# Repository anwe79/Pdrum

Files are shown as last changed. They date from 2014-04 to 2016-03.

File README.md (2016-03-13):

Pdrum
=====

These files contain models of parts for an electronic drum kit.
They are written in OpenSCAD.
Any STL files are merely exports of the default configuration of the models.

Users are encouraged to open the files in OpenSCAD and change parameters to suit their needs.
The models are parametric to a certain degree, and should be scaleable to larger sizes, but this has not been tested. 
The default configuration is printable as is on a MendelMax 3D printer (or other printer of equal or greater print area) and suited for 6" heads.

For now, only the drum base + rim and sensor platform is available.
Hi-hat pedal, kick pedal, clamps and DIY stand are in the works, but don't hold your breath :)
Cymbals will be omitted for now, since the angle makes them difficult to print without support.

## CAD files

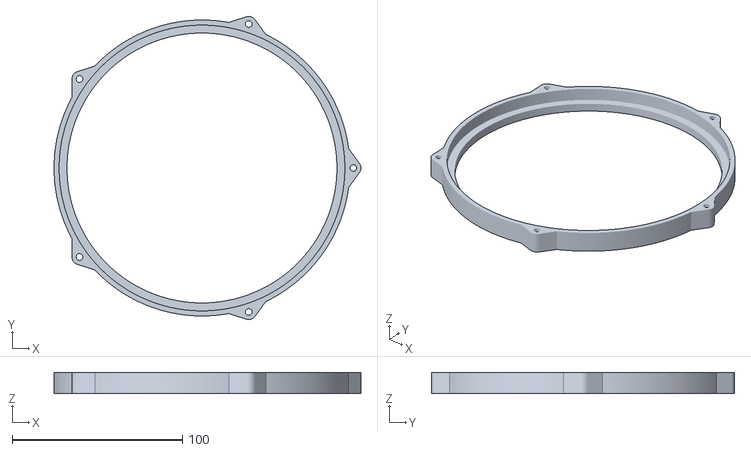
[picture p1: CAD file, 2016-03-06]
drum_base_rim.stl
180.5 x 178.2 x 12.5

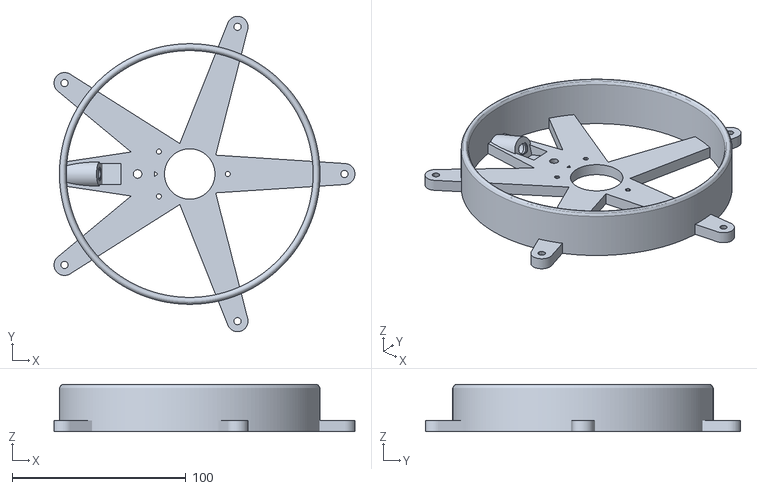
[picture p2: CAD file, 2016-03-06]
drum_base_body.stl
173.1 x 181.4 x 27.0

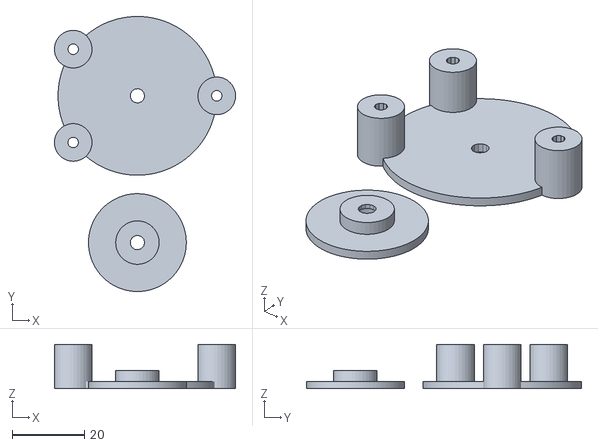
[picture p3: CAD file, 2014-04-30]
drum_base_sensor.stl
50.0 x 75.9 x 12.2

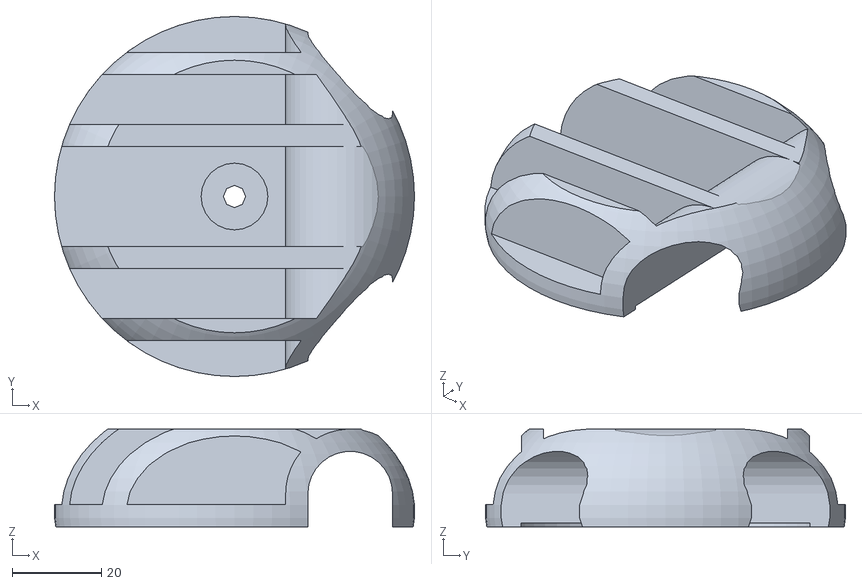
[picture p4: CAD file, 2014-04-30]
pipe_clamp.stl
80.9 x 80.9 x 22.0

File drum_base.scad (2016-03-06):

//Draft of printable electronic drum
//Copyright 2013 Andreas Wettergren

/*
    This program is free software: you can redistribute it and/or modify
    it under the terms of the GNU General Public License as published by
    the Free Software Foundation, either version 3 of the License, or
    (at your option) any later version.

    This program is distributed in the hope that it will be useful,
    but WITHOUT ANY WARRANTY; without even the implied warranty of
    MERCHANTABILITY or FITNESS FOR A PARTICULAR PURPOSE.  See the
    GNU General Public License for more details.

    You should have received a copy of the GNU General Public License
    along with this program.  If not, see <http://www.gnu.org/licenses/>.
*/

use <MCAD/shapes.scad>;
use <MCAD/triangles.scad>;
include <MCAD/nuts_and_bolts.scad>;
$fs=1;
$fa=2;

//All measurements in mm except shell radius due to drum head size conventions
//print_parameters
print_sensor=0;
print_body=0;
print_rim=1;

//shell parameters
inch=25.4;
thickness=4;
or=2.95*inch; //default 6" head, remember to change hoop_or to.
ir=or-(thickness);
shell_h=25;
//bearing parameters
bearing_angle=60;
bearing_r=1.5;
bearing_h=bearing_r/3;
bearing_top=2*sqrt(bearing_h*(2*bearing_r-bearing_h));
triangle_side=(thickness-bearing_top)/2; 
triangle_top=tan(bearing_angle)*triangle_side; 
//misc parameters
strut_h=METRIC_NUT_THICKNESS[4]*2;
sensor_r=13.5;
//Assume M4 for sensor screw, long M3s are hard to find.
//These parameters should cover most M4 screw heads
sensor_screw_head_h=4; 
sensor_screw_head_r=5;
sensor_screw_r=COURSE_METRIC_BOLT_MAJOR_THREAD_DIAMETERS[4]/2;
sensor_mount_screw_r=COURSE_METRIC_BOLT_MAJOR_THREAD_DIAMETERS[3]/2;
sensor_mount_nut_width=METRIC_NUT_AC_WIDTHS[3];
sensor_mount_depth=15;
platform_h=2;
rim_bolt_size=4;
rim_bolt_r=COURSE_METRIC_BOLT_MAJOR_THREAD_DIAMETERS[rim_bolt_size]/2;
rim_bolt_head_h=4;
rim_bolt_head_r=3.5;

//hoop parameters, modeled on triggerhead 6" heads, with some margin.
hoop_t=7;
hoop_or=84;
hoop_h=7;
rim_h=hoop_h+rim_bolt_head_h+1.5;
rim_t=3;
rim_bolt_offset=hoop_or+rim_t+rim_bolt_r;

module bearing_edge() {
  union() {
    //base trapezoid
    rotate_extrude() {
      translate([or-thickness, 0, 0])
      polygon( points=[[0,0], [triangle_side, triangle_top], [triangle_side+bearing_top, triangle_top], [thickness,0]] );
    }
    //top radius
    difference() {
      translate ([0,0,triangle_top-bearing_r+bearing_h])
      rotate_extrude() {
        translate([or-thickness/2, 0, 0])
        circle(r=bearing_r, $fs=0.3); 
      }
      translate ([0,0,triangle_top-bearing_r]) 
      rotate_extrude() {
        translate([or-thickness/2, 0, 0])
        square(bearing_r*2, center=true);
      }
    }
  }
}

module shell() {
  difference() {
    cylinder (h=shell_h, r=or);
    translate ([0,0,-0.5]) cylinder (h=shell_h+1,r=ir);
    translate([-or-1,0,0]) rotate([0,75,0]) cylinder(r=6.5, h=23);
  }
}

module struts() {
  mounting_hole=COURSE_METRIC_BOLT_MAJOR_THREAD_DIAMETERS[5]; 
  mount_offset=or/3;
  difference() {
    union() {
        for (i=[0:4]) {
          rotate([0,0,i*72]) {
            hull() {
              translate ([rim_bolt_offset,0,0]) cylinder(r=METRIC_NUT_AC_WIDTHS[rim_bolt_size]/2+2, h=strut_h);
              translate ([0,sensor_r/2,0]) cylinder(r=METRIC_NUT_AC_WIDTHS[rim_bolt_size]/2+1, h=strut_h);
              translate ([0,-sensor_r/2,0]) cylinder(r=METRIC_NUT_AC_WIDTHS[rim_bolt_size]/2+1, h=strut_h);
            }
          }
        }
      for (i=[0:4]) {
        rotate([0,0,i*72]) {
          translate ([0, -(METRIC_NUT_AC_WIDTHS[rim_bolt_size]+2)/2, 0]) cube(size=[rim_bolt_offset, METRIC_NUT_AC_WIDTHS[rim_bolt_size]+2, strut_h]);
        }
      }
      cylinder(r=sensor_r+2, h=strut_h);
      //mounting/jack strut 
      linear_extrude(height=strut_h) {
        polygon(points=[[mount_offset*cos(144), mount_offset*sin(144)], [mount_offset*cos(216), mount_offset*sin(216)], [or*cos(185),or*sin(185)], [or*cos(175),or*sin(175)]  ]);
      }
      translate([-or,0,0]) rotate([0,75,0]) cylinder(r=7, h=24);
    }
    for (i=[0:4]) {
      rotate([0,0,i*72]) translate ([rim_bolt_offset,0,-0.5]) {
        translate([0,0,METRIC_NUT_THICKNESS[4]+.4]) rotate([0,180,0]) nutHole(4);
        cylinder(r=rim_bolt_r+.1, h=strut_h+1);
      }
    }
    //sensor mount holes
    translate([0,0,-.5]) cylinder(r=sensor_r+1, h=strut_h+1);
    for(i=[0,144,216]) {
      rotate([0,0,i]) translate([sensor_r+sensor_mount_nut_width+2, 0, 0]) {
        translate([0,0,-.5]) cylinder(r=COURSE_METRIC_BOLT_MAJOR_THREAD_DIAMETERS[3]/2, h=sensor_mount_depth+platform_h-strut_h+1);
      }
    }
    //mount and jack holes
    translate([-mount_offset*1.2,0,-.5]) cylinder(r=mounting_hole/2, h=strut_h+1);
    translate([-or-1,0,0]) rotate([0,75,0]) cylinder(r=6.5, h=23);
    translate([-or-1,0,0]) rotate([0,75,0]) cylinder(r=3, h=25);
    translate([-or,0,0]) rotate([0,75,0]) translate([0,0,30]) cube(12, center=true);
    translate([-or,0,0]) rotate([0,75,0]) translate([0,0,23.5]) intersection() {
      cylinder(r=4, h=2);
      cube([6,8,2], center=true);
    }
    translate([-or+12.5,0,-3.5]) cube([25,14,7], center=true);
    translate([-or,0,0]) cube([5,14,15], center=true);
  }
}

module sensor_platform() {
  difference () {
    union() {
      cylinder(r=sensor_r, h=platform_h);
      translate([0,0,+1]) cylinder(r=sensor_screw_head_r+1, h=sensor_screw_head_h);
    }
    translate([0,0,-1]) cylinder(r=sensor_screw_head_r, h=sensor_screw_head_h+1);
    translate([0,0,-1]) cylinder(r=sensor_screw_r, h=sensor_screw_head_h+platform_h+1);
  }
}

module sensor_mount() {
  difference() {
    union() {
      cylinder(r=sensor_r+sensor_mount_nut_width+2, h=platform_h);
      for(i=[0,144,216]) {
        rotate([0,0,i]) translate([sensor_r+sensor_mount_nut_width+2, 0, 0]) {
          cylinder(r=sensor_mount_nut_width/2+2, h=sensor_mount_depth+platform_h-strut_h);
        }
      }
    }
    for(i=[0,144,216]) {
      rotate([0,0,i]) translate([sensor_r+sensor_mount_nut_width+2, 0, 0]) {
        translate([0,0,-.5]) cylinder(r=COURSE_METRIC_BOLT_MAJOR_THREAD_DIAMETERS[3]/2, h=sensor_mount_depth+platform_h-strut_h+1);
        translate([0,0,-.1]) nutHole(3);
      }
    }
    translate([0,0,-.5]) cylinder(r=sensor_screw_r, h=platform_h+1);
  }
} 

module rim() {
  difference() { 
    union () {
      hull() {
        for(i=[0:4]) {
          rotate([0,0,i*72]) translate([rim_bolt_offset,0,0]) cylinder(r=rim_bolt_head_r+1, h=rim_h);
        }
      }
      cylinder(r=hoop_or+rim_t, h=rim_h);
    }
    translate([0,0,-0.5]) cylinder(r=hoop_or-2/3*hoop_t, rim_h-hoop_h+1);
    translate([0,0,rim_h-hoop_h-.5]) cylinder(r=hoop_or, hoop_h+1);
    for (i=[0:4]) {
      rotate([0,0,i*72]) translate([rim_bolt_offset,0,-.5]) cylinder(r=rim_bolt_r, h=rim_h+1);
    }
    for (i=[0:4]) {
      rotate([0,0,i*72]) translate([rim_bolt_offset,0,-0.5]) cylinder(r=rim_bolt_head_r, h=rim_bolt_head_h+1);
    }    
  }
}

if (print_sensor) {
  translate([0,or*2,0]) sensor_platform();
  translate([0,or*2+sensor_r*3,0]) sensor_mount();
}

if (print_body) {
  translate([0,0,shell_h]) bearing_edge();
  shell();
  struts();
}

if (print_rim) {
  translate([0,-rim_bolt_offset*2-rim_bolt_size,0]) rim();
}

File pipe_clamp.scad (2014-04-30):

// Configuration parameters
$fa=6;
//Pipe diameter
Pd=15;
//Screw diameter
Sd=5;
//Washer type
Penny_washer=true;
//Rubber thickness
Rt=2;
//Base thickness
T=5;
//Inner and outer Clearances
Ic=0;
Oc=4;

//Calculated constants

//Washer diameter
Wd=(Penny_washer) ? 3*Sd : 2*Sd;
//Pipe housing diameters
PHod=Pd+T*2+Rt*2;
PHid=Pd+Rt*2;
//Overall diameter
Od=2*PHod+Wd+2*Ic+2*Oc;
//Pipe offset
Po=Wd/2+Ic+Oc+PHod/2;

module brace() {
  translate([-Od/2, 0, T]) cube([Od, T, PHod-Rt-2*T]);
}

module roundoff() {
  translate([0, 0, PHod/2-Rt-2*T+1]) difference() {
    cube([Od+2, Od+2, PHod-Rt+2*T+2], center=true);
    scale([1, 1, 0.7]) sphere(r=Od/2);
  }
}

/*rotate([0, 180, 0])*/ difference() {
  union() {
    //Base
    cylinder(r=Od/2, h=T);
    translate([0, -Od/2, 0]) cube([Po-PHod/2, Od, T]);
    //Pipe Housing
    translate([Po, Od/2, PHid/2-Rt]) rotate([90, 0, 0]) cylinder(r=(PHod)/2, h=Od);
    translate([Po-PHod/2, -Od/2, 0]) cube([PHod, Od, PHid/2-Rt]);
    //Braces
    translate([0,-Od/5,0]) brace();
    translate([0,-Od/2.5,0]) brace();
    translate([0,Od/5-T,0]) brace();
    translate([0,Od/2.5-T,0]) brace();
  } 
  //Pipe hole
  translate([Po, Od/2+0.5, PHid/2-Rt]) rotate([90, 0, 0]) cylinder(r=(PHid)/2, h=Od+1);
  translate([Po, Od, Pd/2]) rotate([90, 0, 0]) cylinder(r=(Pd)/2, h=Od*2);
  translate([Po-(PHid)/2, -Od/2-0.5, -Rt]) cube([PHid, Od+1, PHid/2]);
  //Rubber cutout and base smoothing
  difference() {
    translate([0, 0, -0.1]) cylinder(r=Od/2-Oc, h=Rt/2);
    cylinder(r=Sd, h=T);
  }
  translate([-Od, -Od, -3*T+0.01]) cube([Od*2, Od*2, 3*T]);
  //Washer and screw holes
  translate([0, 0, T-1]) cylinder(r=Wd/2, h=PHod);
  translate([0, 0, -T/2]) cylinder(r=Sd/2,h=2*T);
  roundoff();
}

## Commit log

2013-07-09 Initial commit, rim and sensor platform done, body needs more work.
    [drum_base.scad, drum_base_rim.stl, drum_base_sensor.stl]
2013-07-09 Modified struts
    [drum_base.scad, drum_base_body.stl]
2013-07-09 Added readme and licensing.
    [drum_base.scad]
2013-07-09 fix tabs
    [drum_base.scad]
2013-07-10 Fixed skinny walls around lug nuts.
    [drum_base.scad, drum_base_body.stl]
2013-07-12 New jack mount and switch to standard nuts
    [drum_base.scad, drum_base_body.stl]
2013-07-14 Trim print sizes and sensor platform rework.
    [drum_base.scad, drum_base_sensor.stl]
2014-04-30 Updates and beta clamp
    [drum_base.scad, drum_base_sensor.stl, pipe_clamp.scad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]
2014-04-30 drum_base_sensor.stl should include the platform
    [drum_base.scad, drum_base_sensor.stl]
2016-03-06 Stronger struts and rim rework.
    [drum_base.scad, drum_base_body.stl, drum_base_rim.stl]
2016-03-06 Recess rim bolt heads.
    [drum_base.scad, drum_base_rim.stl]
